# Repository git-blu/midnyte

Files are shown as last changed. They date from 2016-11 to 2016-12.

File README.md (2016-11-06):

# Midnyte LED tablet

Midnyte is an AVR-based resistive touchscreen tablet that uses a 16x24 RGB LED display.
74HC595 shift registers and TLC5940 16-channel PWM LED drivers drive the display and a Semtech SX8652 drives the 4-wire resistive touch panel for user input.
The device can switch between wall power and an internal Li-Ion battery pack.

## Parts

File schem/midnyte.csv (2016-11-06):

Reference | Value | Footprint | Datasheet
P3 | HID | Midnyte:pin_array_4x1_angled
SW3 | +BRIGHTNESS | Midnyte:BUTTON
SW2 | -BRIGHTNESS | Midnyte:BUTTON
RBRIGHT-1 | 100 | SMD:SMD-0402
RDIM-1 | 100 | SMD:SMD-0402
SW1 | RESET | Midnyte:BUTTON
CUCAP1 | 1uF | SMD:SMD-0402
CXTAL1 | 18pF | SMD:SMD-0402
CXTAL2 | 18pF | SMD:SMD-0402
RRESET+1 | 10k | SMD:SMD-0402
RRESET-1 | 100 | SMD:SMD-0402
CVBUS1 | 0.1uF | SMD:SMD-0402
C2 | 0.1uF | SMD:SMD-0402
C4 | 0.1uF | SMD:SMD-0402
C6 | 0.1uF | SMD:SMD-0402
C8 | 0.1uF | SMD:SMD-0402
C10 | 0.1uF | SMD:SMD-0402
C12 | 0.1uF | SMD:SMD-0402
P4 | AVR_JTAG | Midnyte:3220-10-0100-00
X1 | XTAL-2 | Midnyte:CSM-7X
CHID1 | 1uF | SMD:SMD-0402
CHID2 | 0.1uF | SMD:SMD-0402
RTCK1 | 100k | SMD:SMD-0402
RTDO1 | 100k | SMD:SMD-0402
RTMS1 | 100k | SMD:SMD-0402
RTDI1 | 100k | SMD:SMD-0402
U1 | ATmega32U4 | DFN | QFN:QFN-44-1EP
RBRIGHT+1 | 10k | SMD:SMD-0402
RDIM+1 | 10k | SMD:SMD-0402
CBRIGHT1 | 0.1uF | SMD:SMD-0402
CDIM1 | 0.1uF | SMD:SMD-0402
CRESET1 | 0.1uF | SMD:SMD-0402
CON1 | USB-MINI-B | Midnyte:10033526-N3212LF
C1 | 0.1uF | SMD:SMD-0402
C3 | 0.1uF | SMD:SMD-0402
C5 | 0.1uF | SMD:SMD-0402
C7 | 0.1uF | SMD:SMD-0402
C9 | 0.1uF | SMD:SMD-0402
C11 | 0.1uF | SMD:SMD-0402
U4 | 23LC1024 | SOIC:SOIC-8_3.9x4.9mm_Pitch1.27mm
U5 | M25P80 | Midnyte:VDFN-8
RFPROT1 | 10k | SMD:SMD-0402
P1 | HOLE-M3 | Midnyte:HOLE-M3
P2 | HOLE-M3 | Midnyte:HOLE-M3
RHOLD2 | 10k | SMD:SMD-0402
RHOLD1 | 10k | SMD:SMD-0402
U3 | 74HC42 | SOIC:SOIC-16_3.9x9.9mm_Pitch1.27mm
U2 | SX8652 | Midnyte:TDFN14
RNIRQ1 | 10k | SMD:SMD-0402
U8 | LT1939 | Midnyte:DFN12
U7 | LTC4412 | Midnyte:TSOT-23
U6 | MAX8600A | Midnyte:TDFN14
U10 | NCP1529 | Midnyte:UDFN6
U9 | NCP1529 | Midnyte:UDFN6
CPSELECT1 | 47uF | SMD:SMD-0805
CPMIC_IN1 | 2.2uF | SMD:SMD-0402
CSS1 | 0.47uF | SMD:SMD-0402
CVC1 | 220pF | SMD:SMD-0402
RVC1 | 49.9k | SMD:SMD-0402
RRT1 | 40.2k | SMD:SMD-0402
CPMIC1 | 0.47uF | SMD:SMD-0402
L1 | 4.7uH | Midnyte:ASPI-0530LR-4R7M-T2
RPMIC5 | 42.2k | SMD:SMD-0402
RPMIC7 | 8.06k | SMD:SMD-0402
CPMIC3 | 22uF | SMD:SMD-0805
RPMIC3 | 8.06k | SMD:SMD-0402
RPMIC4 | 100k | SMD:SMD-0402
RPMIC6 | 8.06k | SMD:SMD-0402
CPMIC2 | 1uF | SMD:SMD-0402
RPMIC2 | 42.2k | SMD:SMD-0402
CRAIL2 | 10uF | SMD:SMD-0402
CRAIL1 | 10uF | SMD:SMD-0402
CBUCK1 | 4.7uF | SMD:SMD-0402
CBUCK2 | 4.7uF | SMD:SMD-0402
L3 | 2.2uH | Midnyte:LTF5022T-2R2N3R2-LC
L2 | 2.2uH | Midnyte:LTF5022T-2R2N3R2-LC
RFB3 | 4.32M | SMD:SMD-0402
RFB5 | 597k | SMD:SMD-0402
RFB1 | 2.7M | SMD:SMD-0402
RFB2 | 597k | SMD:SMD-0402
D2 | SCHOTTKY | Diodes:Diode-SMA_Standard
Q1 | FQP27P06 | SOT:SOT23_Transistor_RevB_14Mar2014
CCT1 | 680nF | SMD:SMD-0402
RSETI1 | 2k | SMD:SMD-0402
CBAT1 | 2.2uF | SMD:SMD-0402
TH1 | 10k@25C | SMD:SMD-0402
RFLT1 | 100k | SMD:SMD-0402
RCHG1 | 660 | SMD:SMD-0402
D1 | DIODE | SMD:SMD-0402
Q2 | FQP27P06 | SOT:SOT23_Transistor_RevB_14Mar2014
D5 | DIODE | SMD:SMD-0402
D3 | SCHOTTKY | Diodes:Diode-SMA_Standard
D4 | SCHOTTKY | Diodes:Diode-SMA_Standard
RFB4 | 80k | SMD:SMD-0402
CFB2 | 18pF | SMD:SMD-0402
CFB1 | 18pF | SMD:SMD-0402
RPMIC1 | 10k | SMD:SMD-0402
RPOK1 | 10k | SMD:SMD-0402
SW4 | POWER | Midnyte:TO-220
REN1 | 10k | SMD:SMD-0402
RPOWER1 | 10k | SMD:SMD-0402
P5 | BATTERY | Midnyte:1954097-1
K1 | WALL | Midnyte:PJ-002AH-SMT
Q3 | N-CHANNEL_FET | SOT:SOT23_Transistor_RevB_14Mar2014
RPSTATUS1 | 10k | SMD:SMD-0402
CPOWER1 | 0.1uF | SMD:SMD-0402
P6 | ROW0L | Midnyte:pin_array_8x1
P7 | ROW0R | Midnyte:pin_array_8x1
P8 | ROW1L | Midnyte:pin_array_8x1
P9 | ROW1R | Midnyte:pin_array_8x1
P10 | ROW2L | Midnyte:pin_array_8x1
P11 | ROW2R | Midnyte:pin_array_8x1
U11 | 74HC595CS | SMD:TSSOP-16
U14 | 74HC595CS | SMD:TSSOP-16
U12 | 74HC595CS | SMD:TSSOP-16
U15 | 74HC595CS | SMD:TSSOP-16
U13 | 74HC595CS | SMD:TSSOP-16
U16 | 74HC595CS | SMD:TSSOP-16
U17 | TLC5940 | DFN | QFN:QFN-32-1EP
U18 | TLC5940 | DFN | QFN:QFN-32-1EP
U19 | TLC5940 | DFN | QFN:QFN-32-1EP
P12 | RED0L | Midnyte:pin_array_8x1
P13 | RED0R | Midnyte:pin_array_8x1
P14 | GREEN0L | Midnyte:pin_array_8x1
P15 | GREEN0R | Midnyte:pin_array_8x1
P16 | BLUE0L | Midnyte:pin_array_8x1
P17 | BLUE0R | Midnyte:pin_array_8x1
RXERR1 | 10k | SMD:SMD-0402
RXERR2 | 10k | SMD:SMD-0402
RXERR3 | 10k | SMD:SMD-0402
CTLC1 | 0.1uF | SMD:SMD-0402
CTLC2 | 0.1uF | SMD:SMD-0402
CTLC3 | 0.1uF | SMD:SMD-0402
IREF1 | 7.68k | SMD:SMD-0402
IREF2 | 7.68k | SMD:SMD-0402
IREF3 | 7.68k | SMD:SMD-0402
RBLANK1 | 10k | SMD:SMD-0402
RBLANK2 | 10k | SMD:SMD-0402
RBLANK3 | 10k | SMD:SMD-0402
U20 | TLC5940 | DFN | QFN:QFN-32-1EP
U21 | TLC5940 | DFN | QFN:QFN-32-1EP
U22 | TLC5940 | DFN | QFN:QFN-32-1EP
P18 | RED1L | Midnyte:pin_array_8x1
P19 | RED1R | Midnyte:pin_array_8x1
P20 | GREEN1L | Midnyte:pin_array_8x1
P21 | GREEN1R | Midnyte:pin_array_8x1
P22 | BLUE1L | Midnyte:pin_array_8x1
P23 | BLUE1R | Midnyte:pin_array_8x1
RXERR4 | 10k | SMD:SMD-0402
RXERR5 | 10k | SMD:SMD-0402
RXERR6 | 10k | SMD:SMD-0402
CTLC4 | 0.1uF | SMD:SMD-0402
CTLC5 | 0.1uF | SMD:SMD-0402
CTLC6 | 0.1uF | SMD:SMD-0402
IREF4 | 7.68k | SMD:SMD-0402
IREF5 | 7.68k | SMD:SMD-0402
IREF6 | 7.68k | SMD:SMD-0402
RBLANK4 | 10k | SMD:SMD-0402
RBLANK5 | 10k | SMD:SMD-0402
RBLANK6 | 10k | SMD:SMD-0402
U23 | TLC5940 | DFN | QFN:QFN-32-1EP
U24 | TLC5940 | DFN | QFN:QFN-32-1EP
U25 | TLC5940 | DFN | QFN:QFN-32-1EP
P24 | RED2L | Midnyte:pin_array_8x1
P25 | RED2R | Midnyte:pin_array_8x1
P26 | GREEN2L | Midnyte:pin_array_8x1
P27 | GREEN2R | Midnyte:pin_array_8x1
P28 | BLUE2L | Midnyte:pin_array_8x1
P29 | BLUE2R | Midnyte:pin_array_8x1
RXERR7 | 10k | SMD:SMD-0402
RXERR8 | 10k | SMD:SMD-0402
RXERR9 | 10k | SMD:SMD-0402
CTLC7 | 0.1uF | SMD:SMD-0402
CTLC8 | 0.1uF | SMD:SMD-0402
CTLC9 | 0.1uF | SMD:SMD-0402
IREF7 | 7.68k | SMD:SMD-0402
IREF8 | 7.68k | SMD:SMD-0402
IREF9 | 7.68k | SMD:SMD-0402
RBLANK7 | 10k | SMD:SMD-0402
RBLANK8 | 10k | SMD:SMD-0402
RBLANK9 | 10k | SMD:SMD-0402

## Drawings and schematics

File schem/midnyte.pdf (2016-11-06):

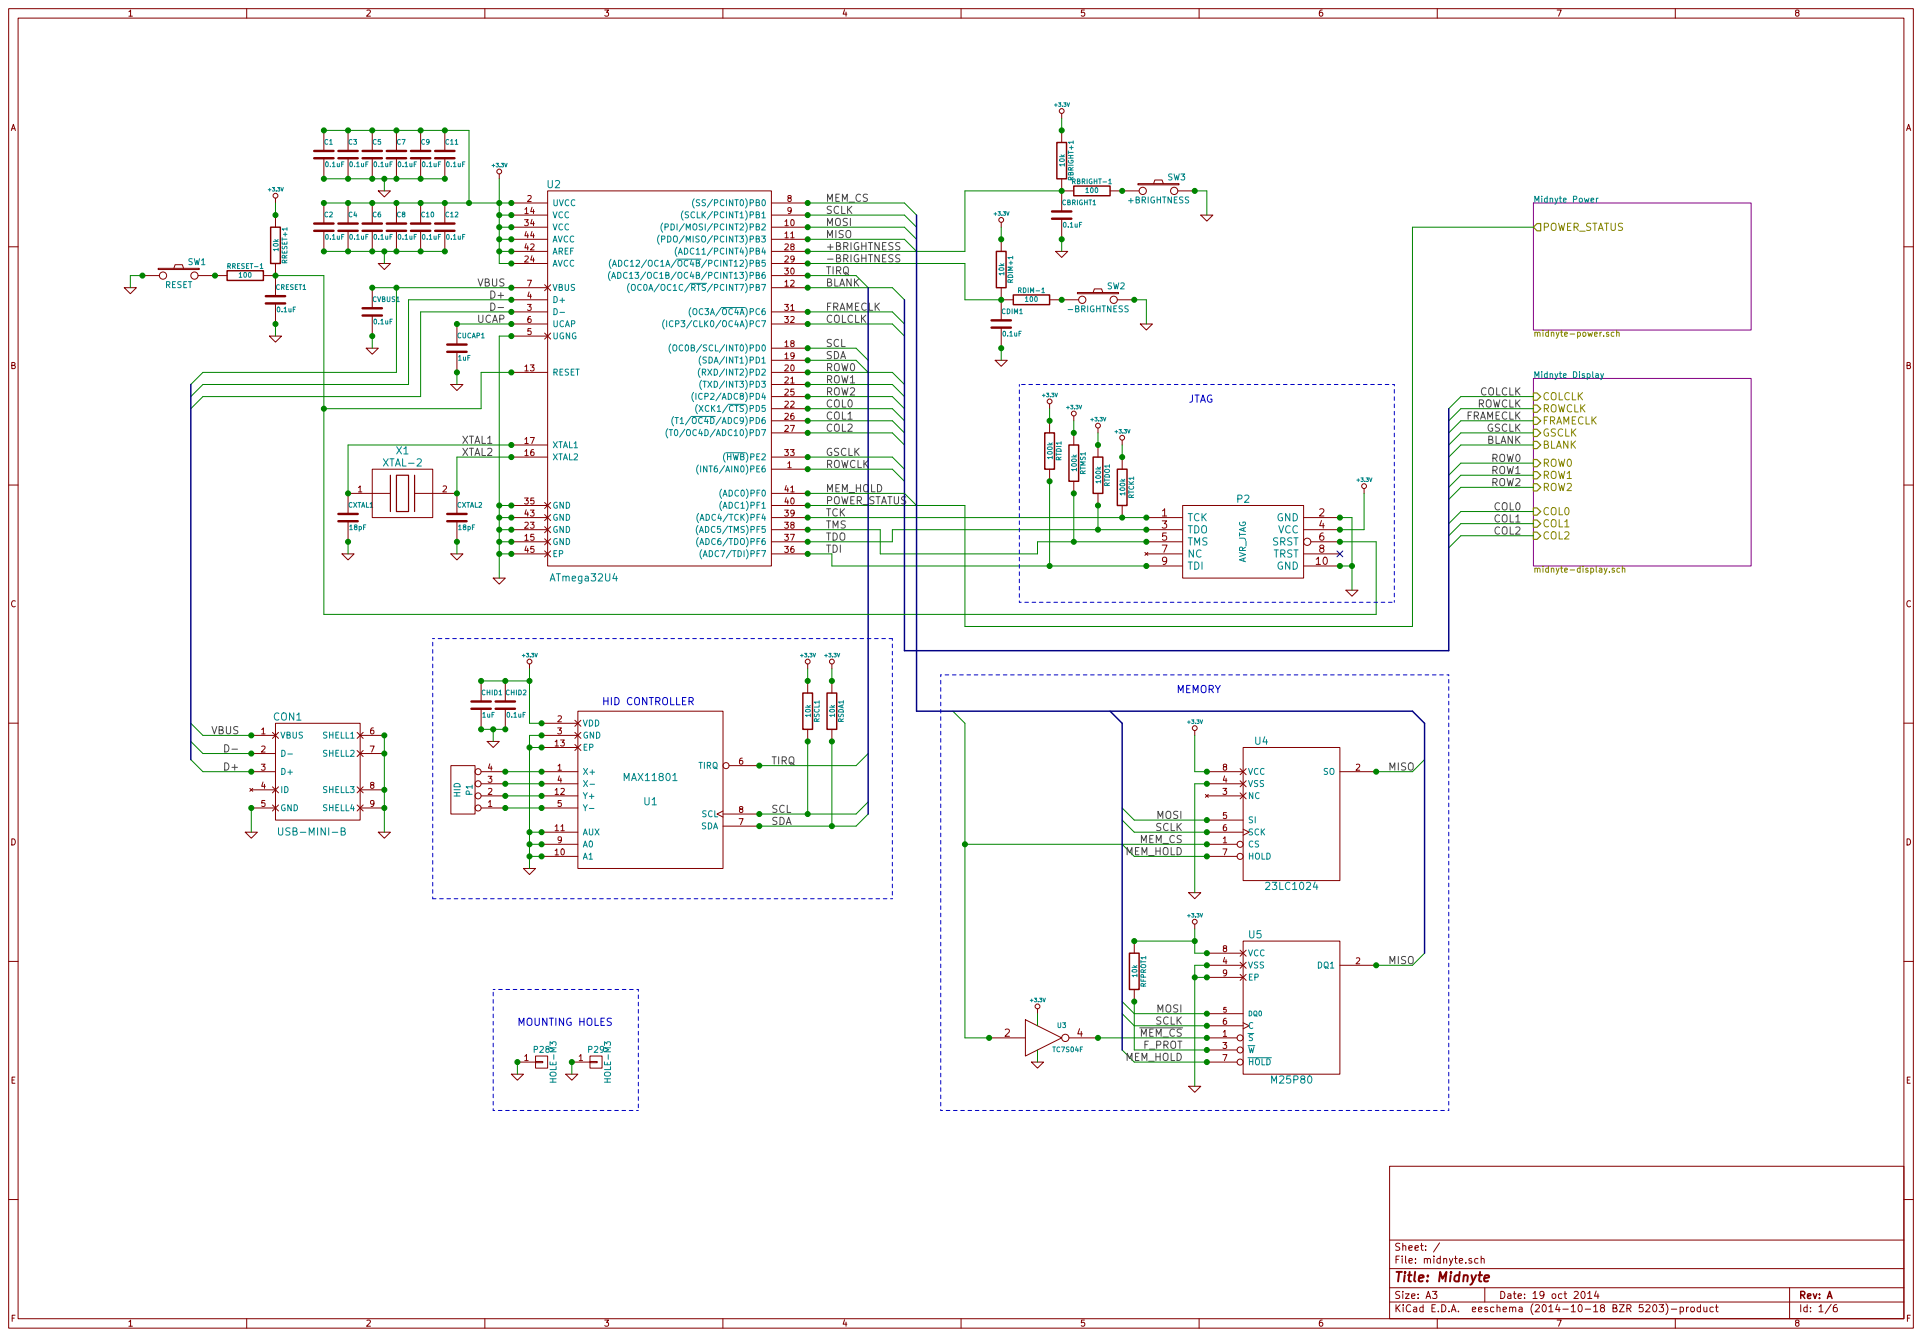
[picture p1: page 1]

+3.3V | JTAG

TCK

File: midnyte.sch Sheet: /
Id: 1/6 Title: Midnyte

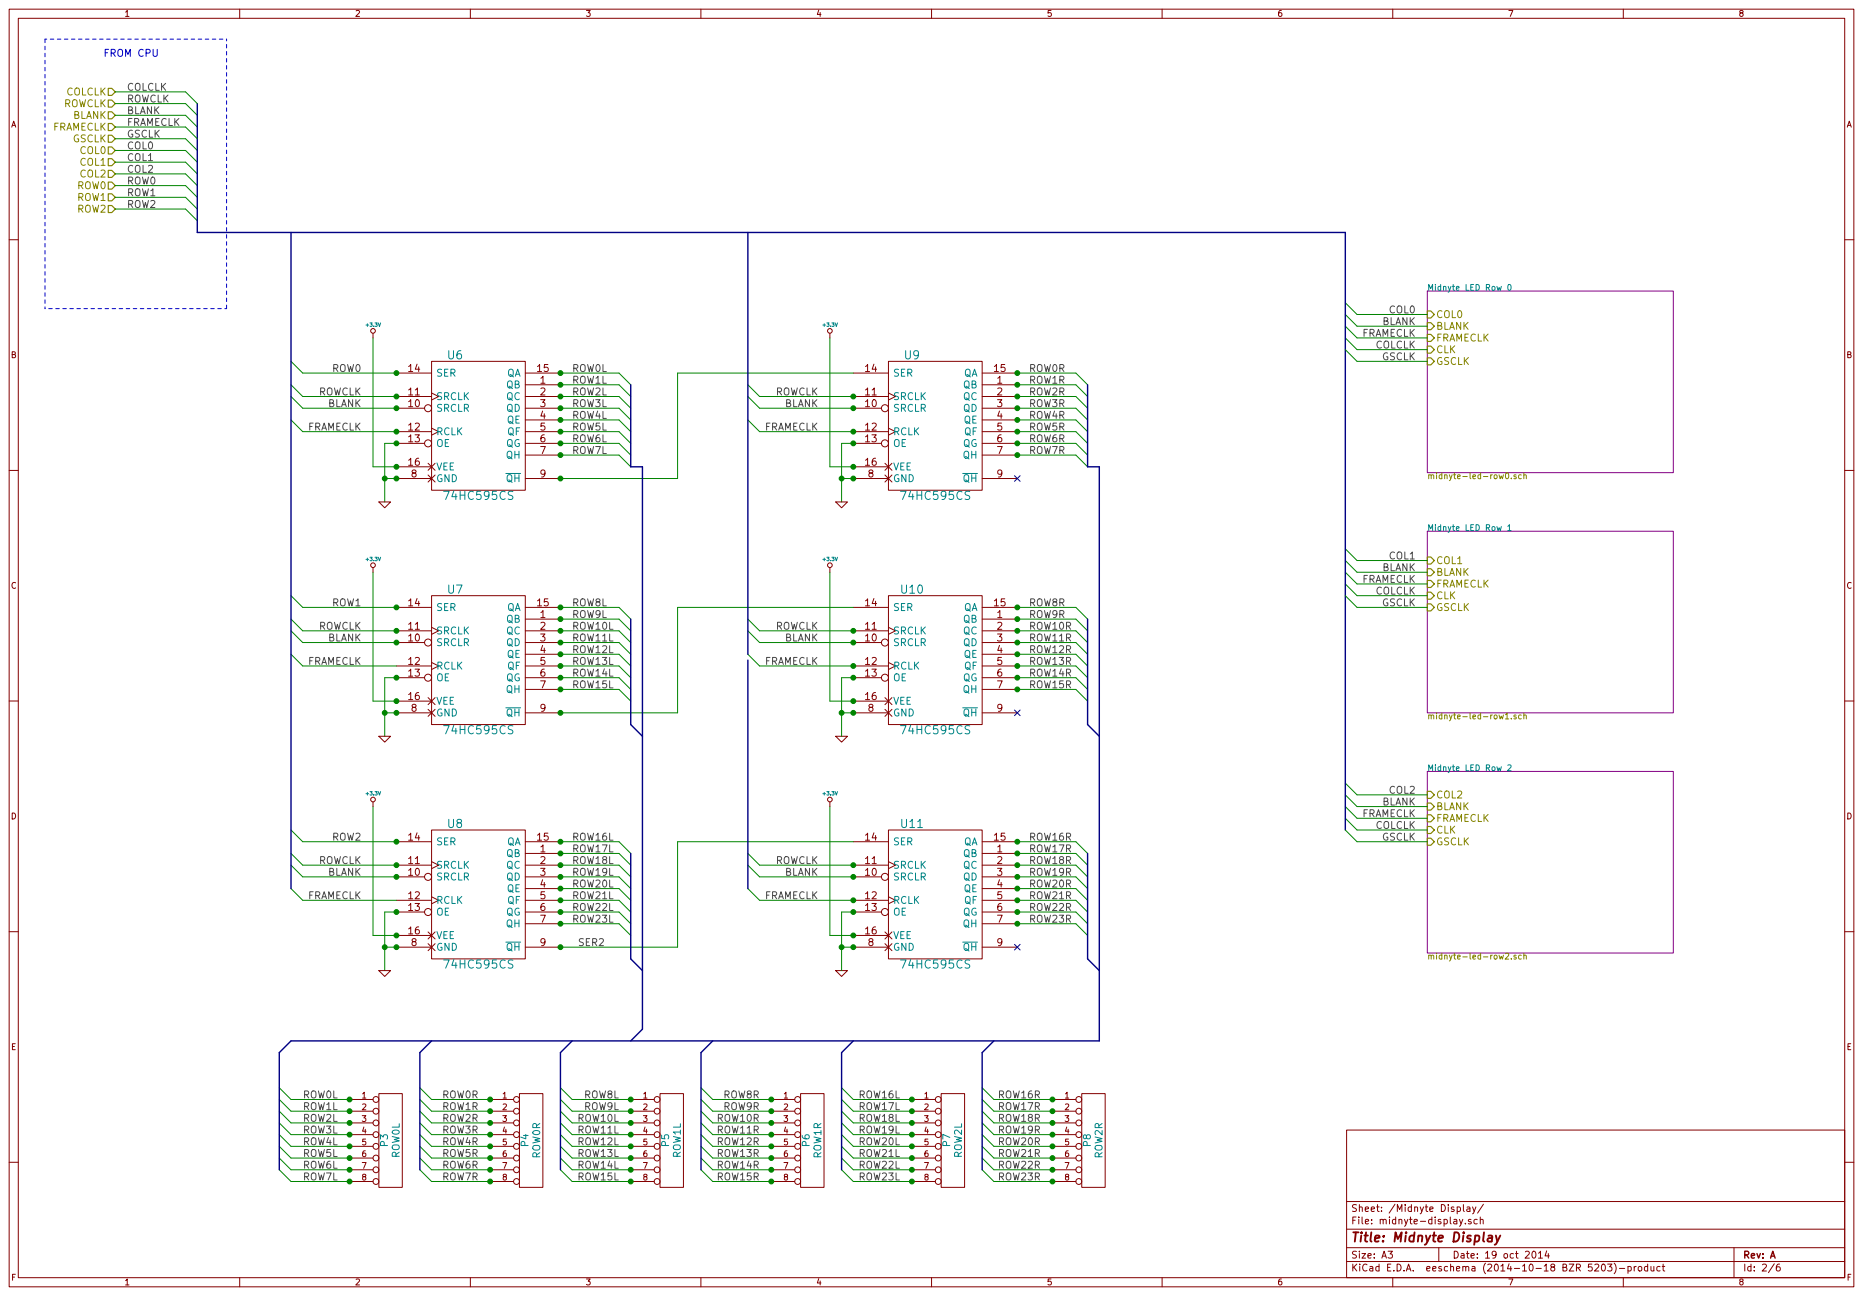
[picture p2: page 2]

Midnyte LED Row 0 midnyte-led-row0.sch COL0 BLANK
FRAMECLK COLCLK COL0 BLANK
FRAMECLK COLCLK COL2 BLANK
FRAMECLK CLK GSCLK Midnyte LED Row 2 midnyte-led-row2.sch COL2 BLANK

Midnyte LED Row 1 midnyte-led-row1.sch COL1 BLANK
FRAMECLK GSCLK

File: midnyte-display.sch Sheet: /Midnyte Display/
Id: 2/6 Title: Midnyte Display

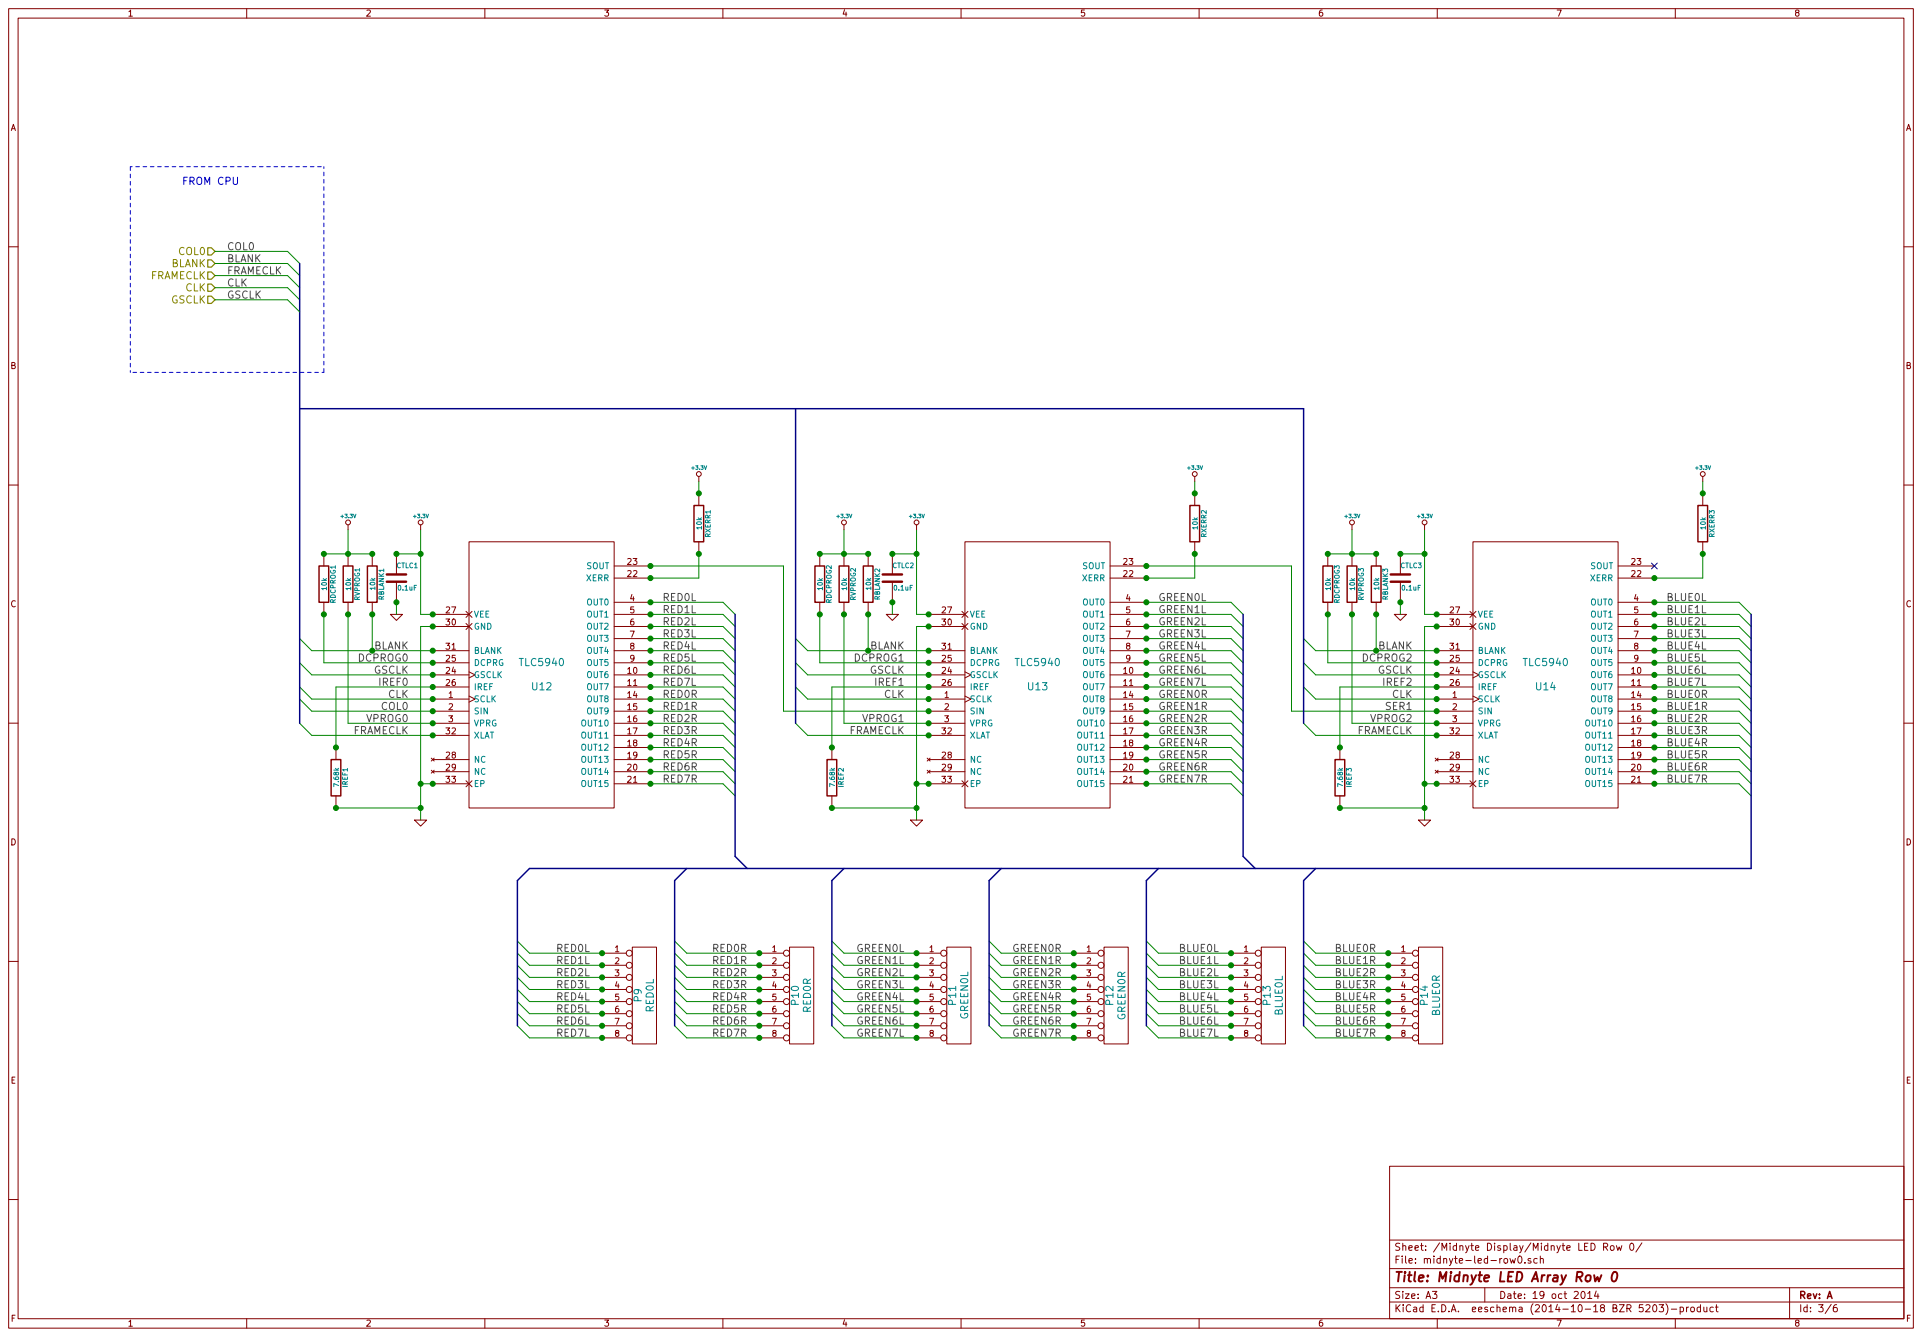
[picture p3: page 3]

File: midnyte-led-row0.sch Sheet: /Midnyte Display/Midnyte LED Row 0/
Id: 3/6 Title: Midnyte LED Array Row 0

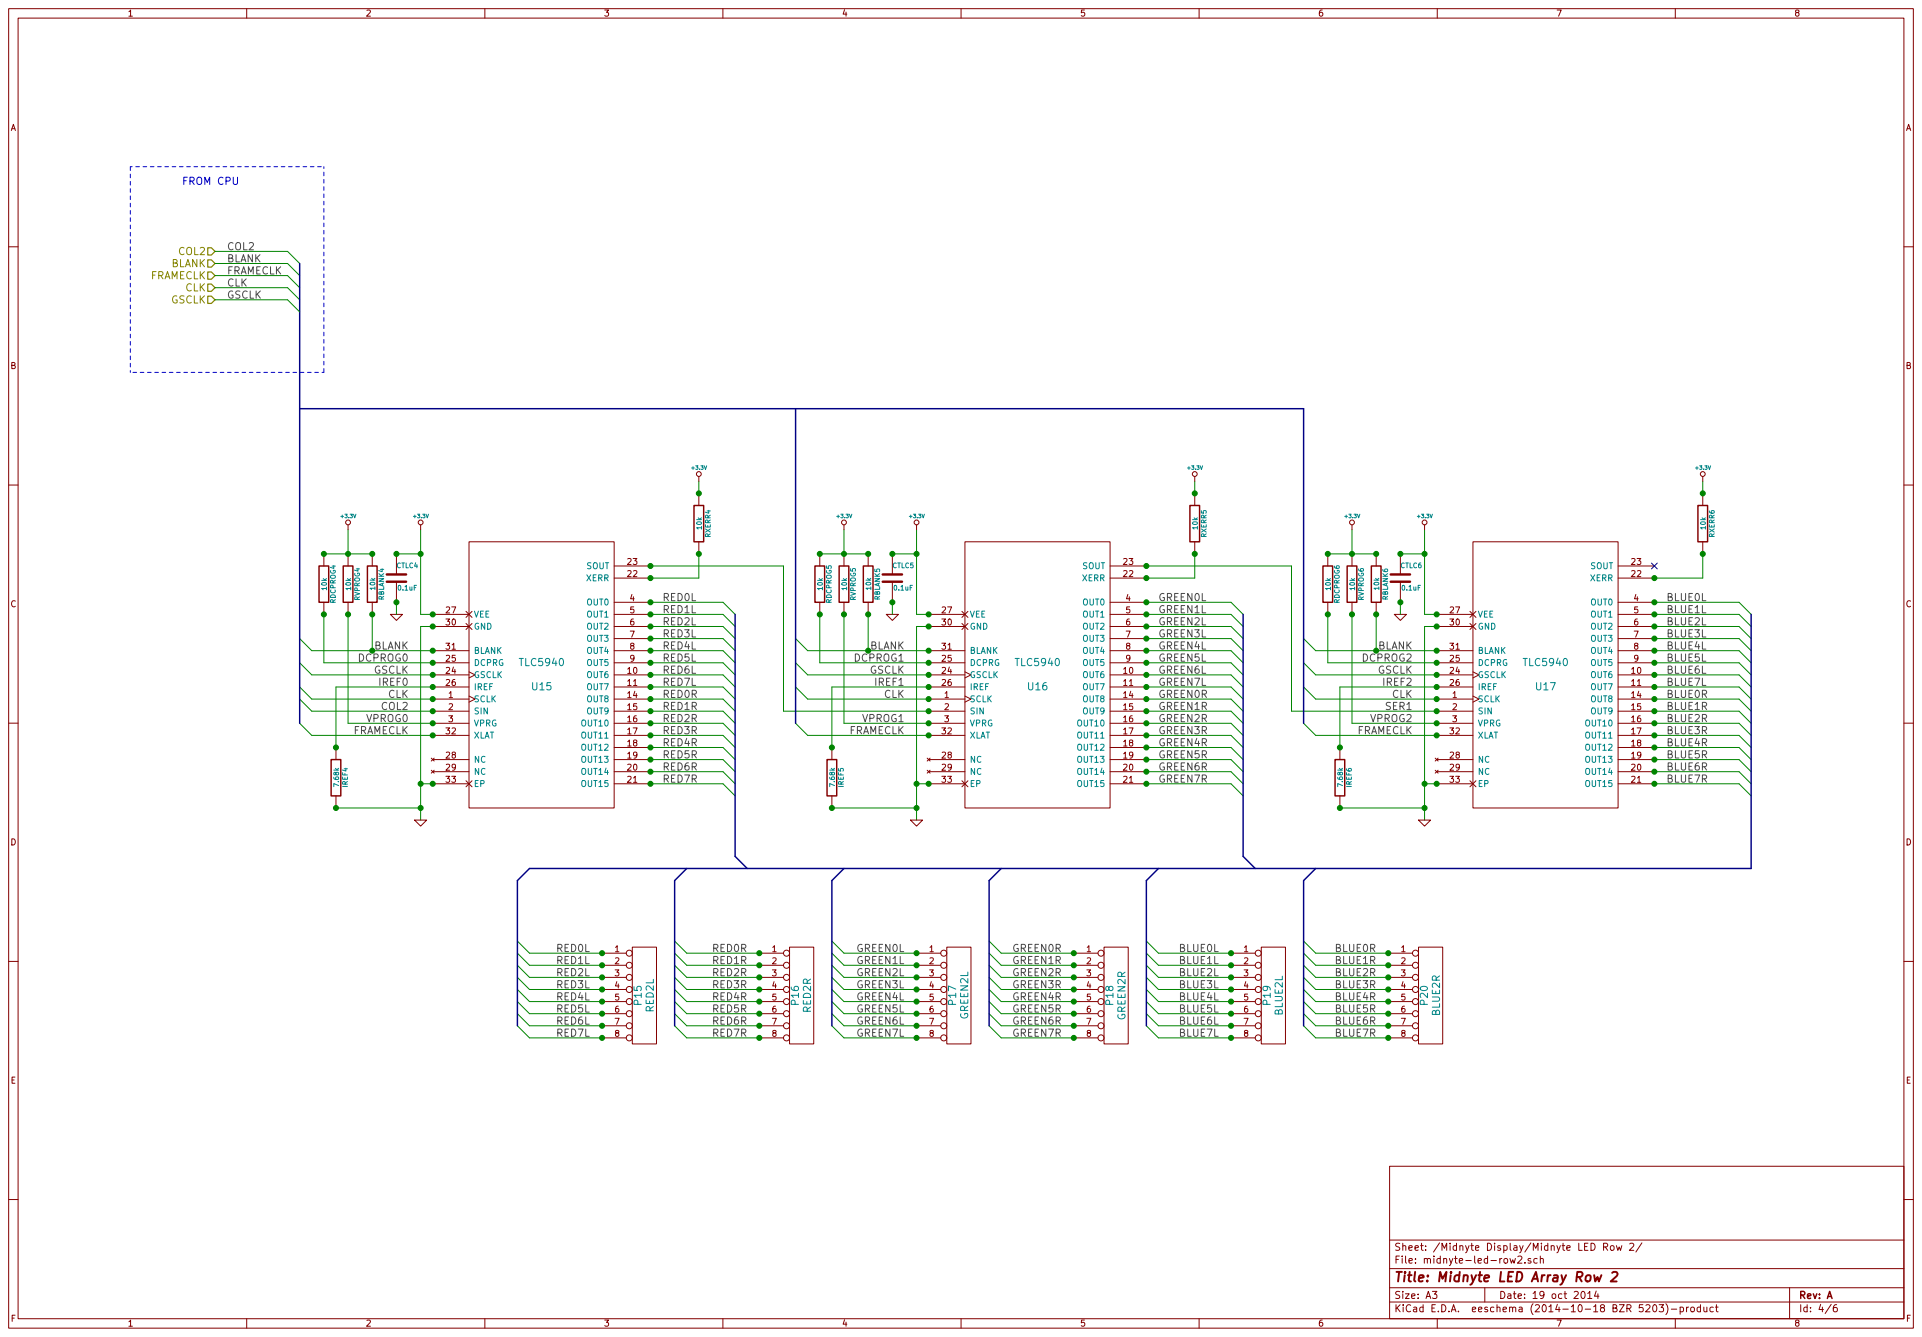
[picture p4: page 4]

File: midnyte-led-row2.sch Sheet: /Midnyte Display/Midnyte LED Row 2/
Id: 4/6 Title: Midnyte LED Array Row 2

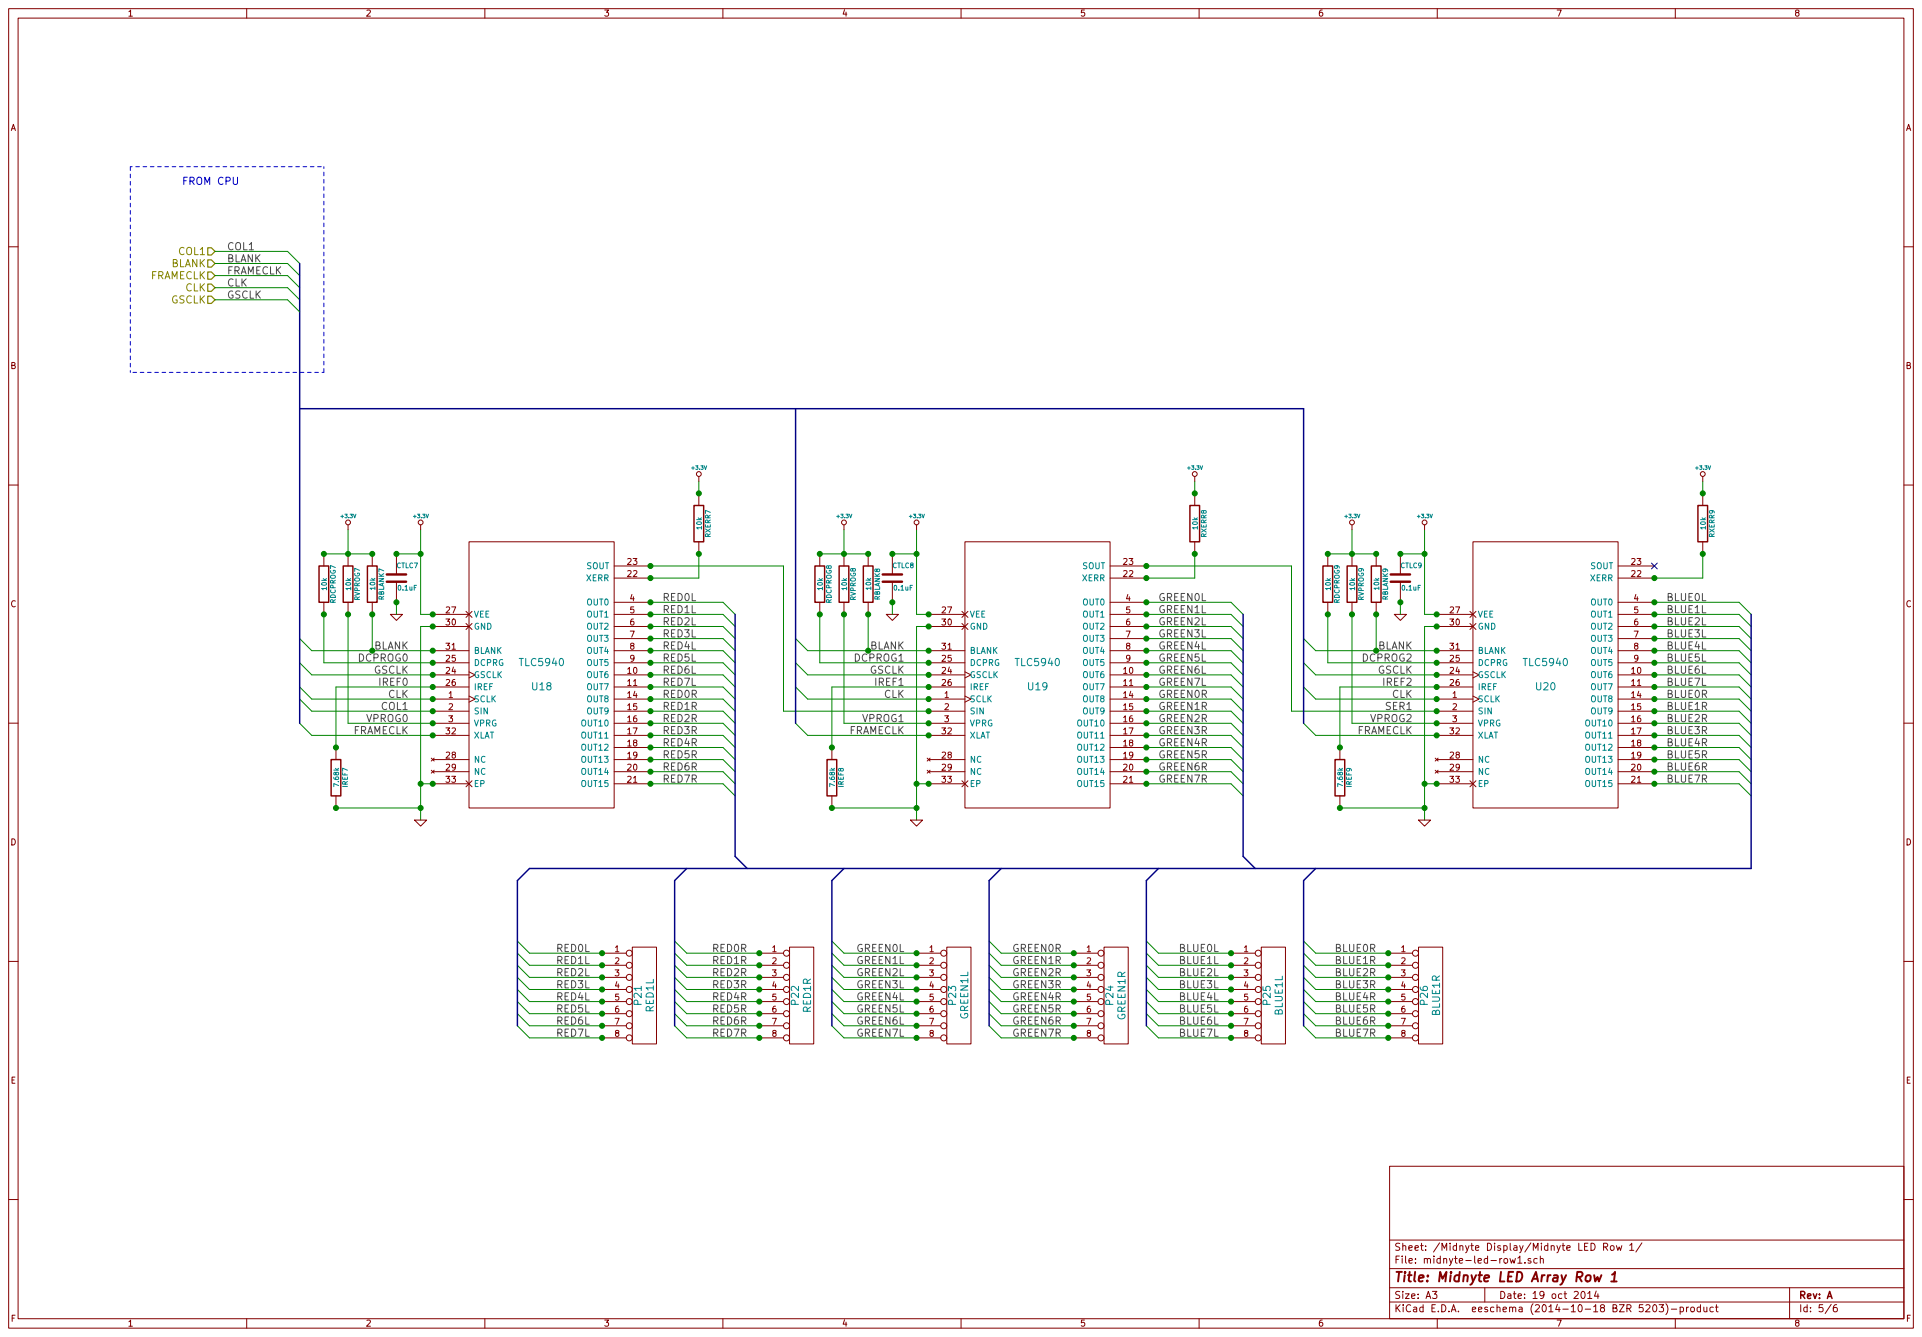
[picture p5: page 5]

File: midnyte-led-row1.sch Sheet: /Midnyte Display/Midnyte LED Row 1/
Id: 5/6 Title: Midnyte LED Array Row 1

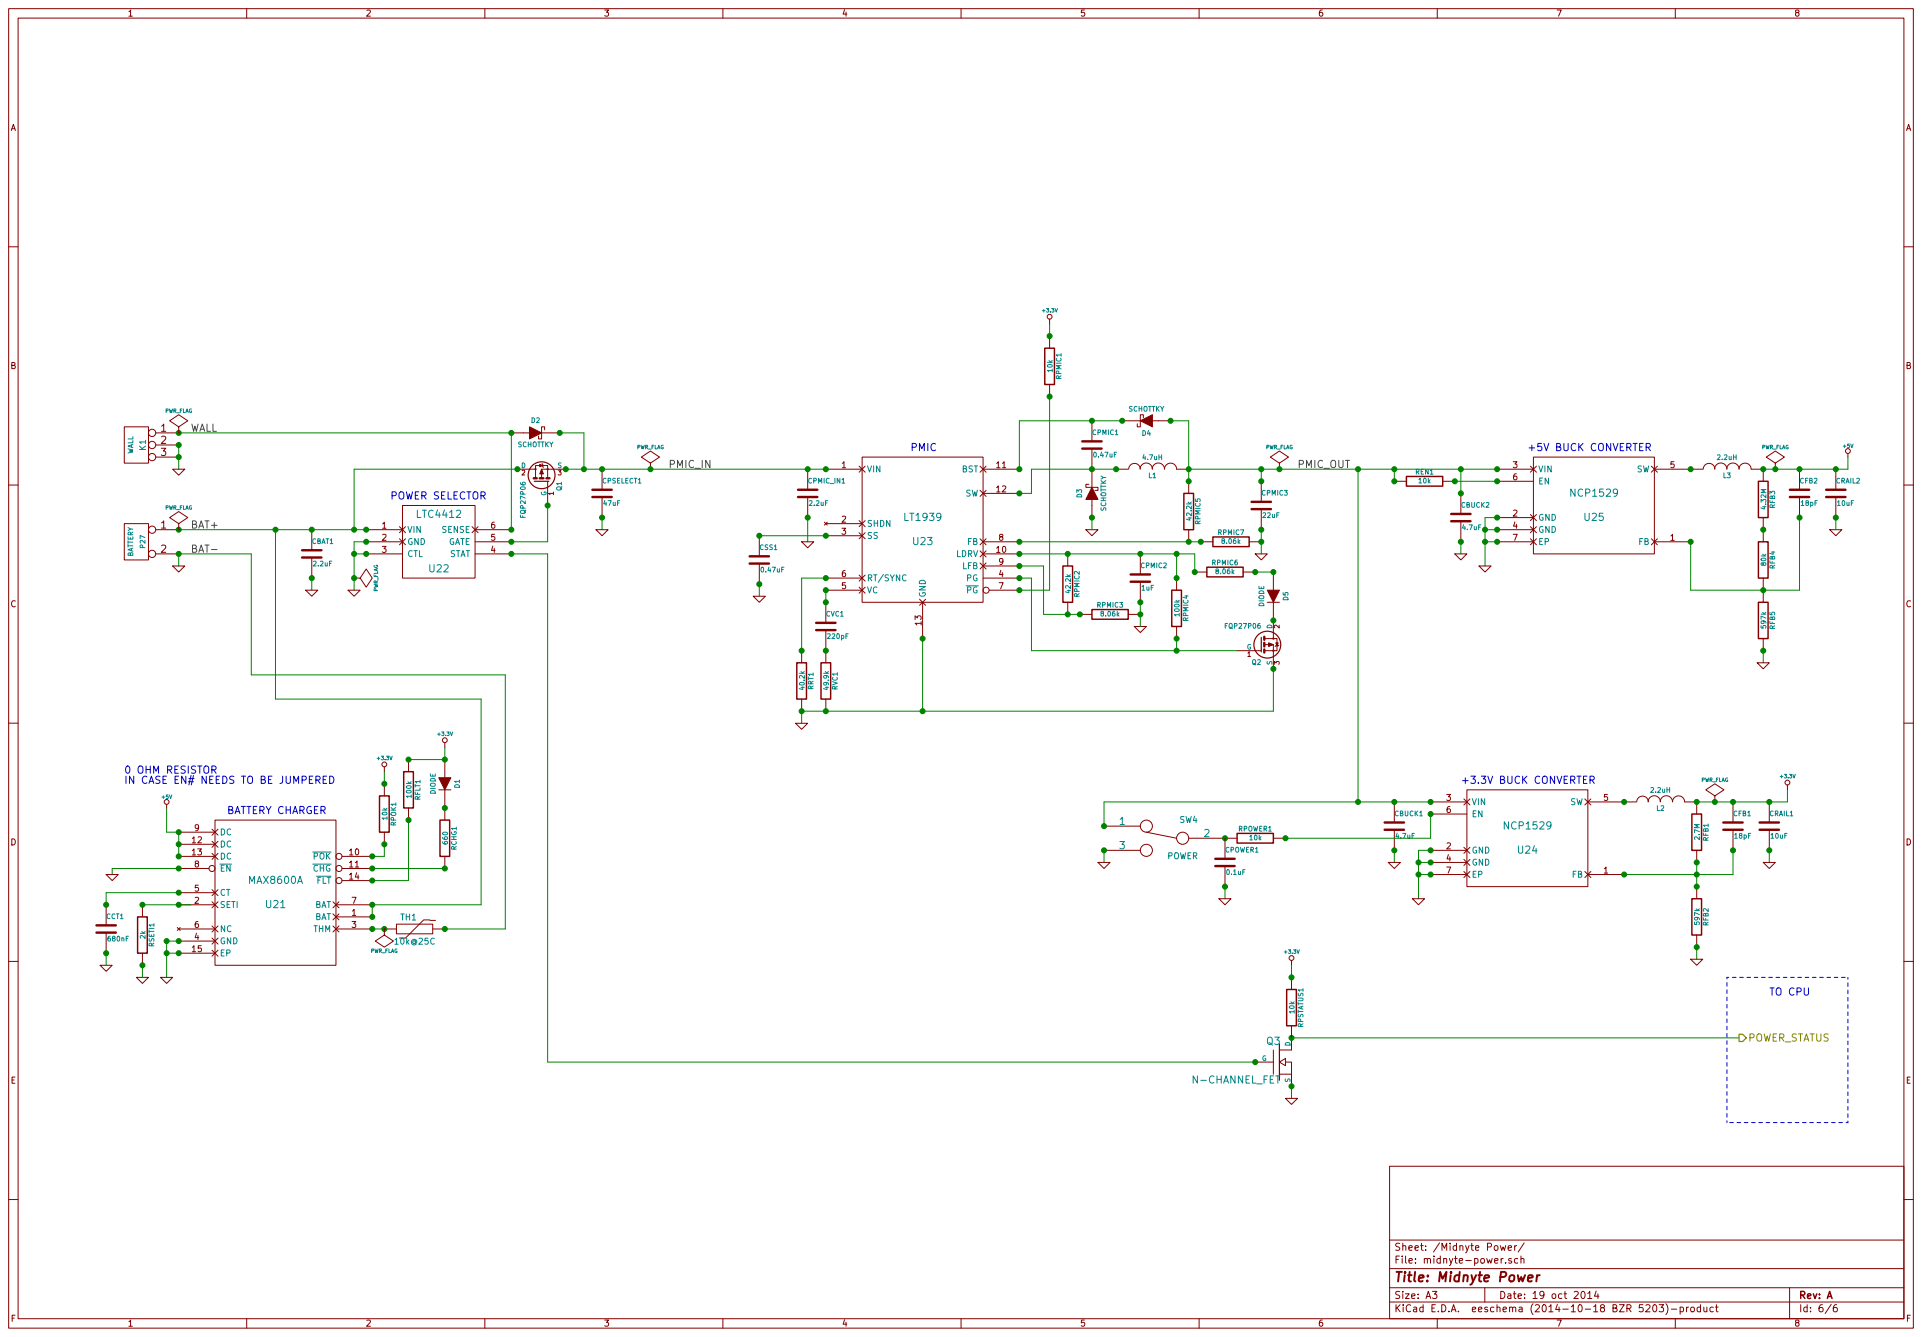
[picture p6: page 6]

IN CASE EN# NEEDS TO BE JUMPERED

Id: 6/6 Title: Midnyte Power File: midnyte-power.sch Sheet: /Midnyte Power/

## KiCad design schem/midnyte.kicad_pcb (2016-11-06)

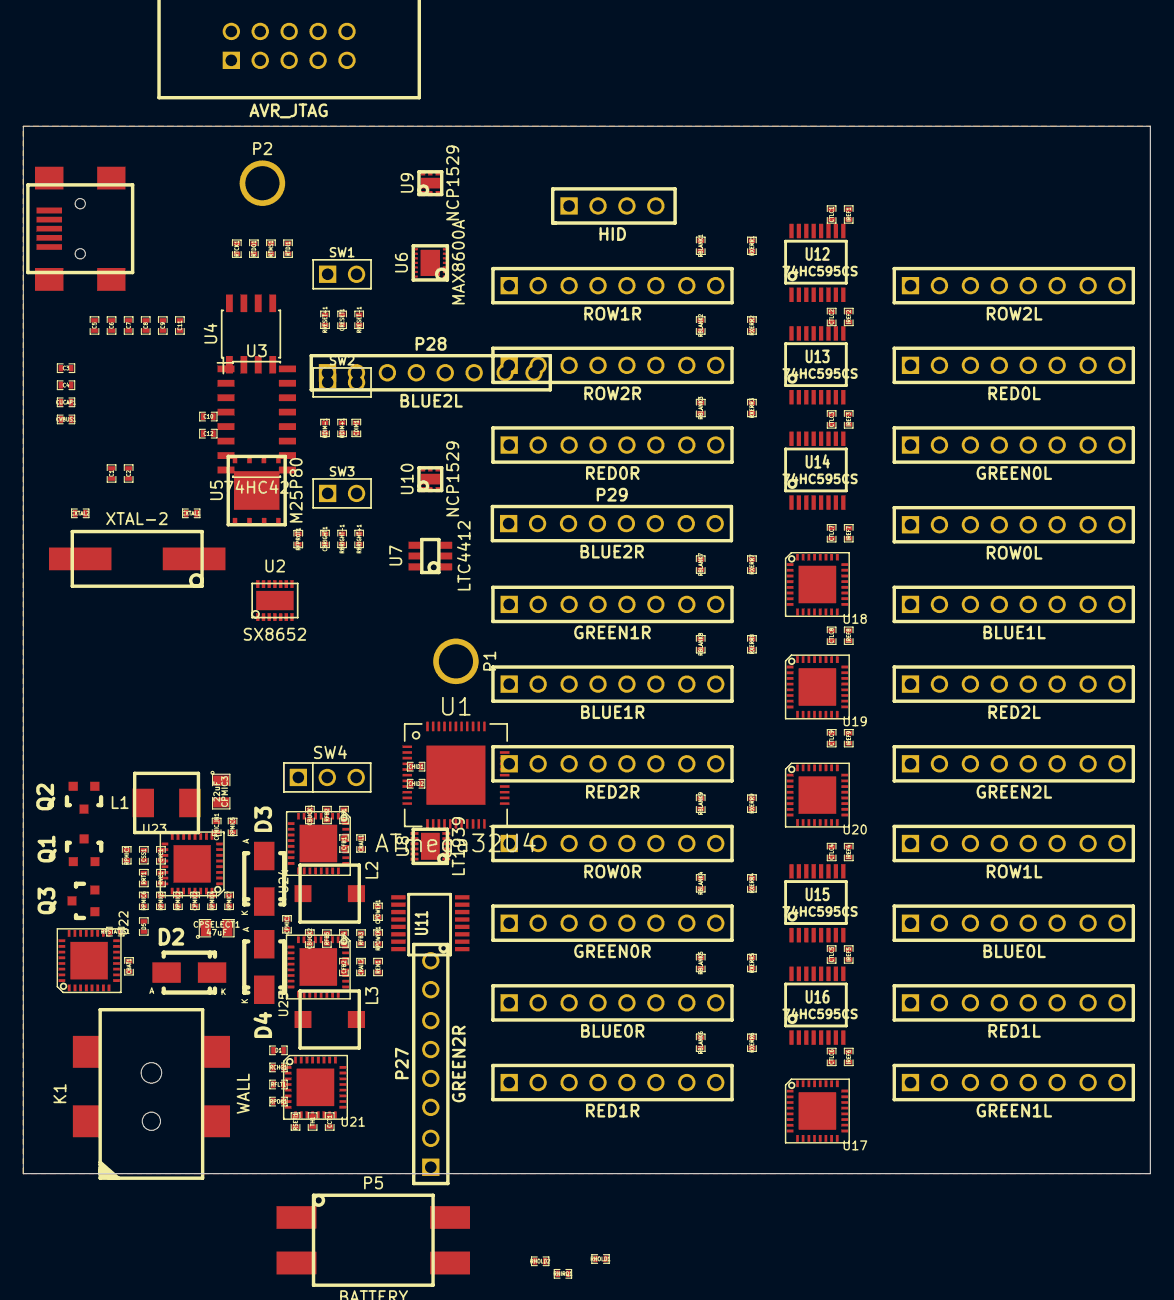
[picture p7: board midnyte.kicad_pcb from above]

Board: 4 copper layers, 99.0 x 92.0 mm, 181 parts (0 on the bottom side), 302 nets, no tracks yet.

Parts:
C1, C2, C3, C4, C5, C6, C7, C8, C9, C10, C11, C12: 0.1uF; SMD-0402
CBAT1: 2.2uF; SMD-0402
CBRIGHT1: 0.1uF; SMD-0402
CBUCK1, CBUCK2: 4.7uF; SMD-0402
CCT1: 680nF; SMD-0402
CDIM1: 0.1uF; SMD-0402
CFB1, CFB2: 18pF; SMD-0402
CHID1: 1uF; SMD-0402
CHID2: 0.1uF; SMD-0402
CON1: USB-MINI-B; 10033526-N3212LF
CPMIC1: 0.47uF; SMD-0402
CPMIC2: 1uF; SMD-0402
CPMIC3: 22uF; SMD-0805
CPMIC_IN1: 2.2uF; SMD-0402
CPOWER1: 0.1uF; SMD-0402
CPSELECT1: 47uF; SMD-0805
CRAIL1, CRAIL2: 10uF; SMD-0402
CRESET1: 0.1uF; SMD-0402
CSS1: 0.47uF; SMD-0402
CTLC1, CTLC2, CTLC3, CTLC4, CTLC5, CTLC6, CTLC7, CTLC8, CTLC9: 0.1uF; SMD-0402
CUCAP1: 1uF; SMD-0402
CVBUS1: 0.1uF; SMD-0402
CVC1: 220pF; SMD-0402
CXTAL1, CXTAL2: 18pF; SMD-0402
D1, D5: DIODE; SMD-0402
D2, D3, D4: SCHOTTKY; Diode-SMA_Standard
IREF1, IREF2, IREF3, IREF4, IREF5, IREF6, IREF7, IREF8, IREF9: 7.68k; SMD-0402
K1: WALL; PJ-002AH-SMT
L1: 4.7uH; ASPI-0530LR-4R7M-T2
L2, L3: 2.2uH; LTF5022T-2R2N3R2-LC
P1, P2: HOLE-M3
P3: HID; pin_array_4x1
P4: AVR_JTAG; 302-S101
P5: BATTERY; 1954097-1
P6: ROW0L; pin_array_8x1
P7: ROW0R; pin_array_8x1
P8: ROW1L; pin_array_8x1
P9: ROW1R; pin_array_8x1
P10: ROW2L; pin_array_8x1
P11: ROW2R; pin_array_8x1
P12: RED0L; pin_array_8x1
P13: RED0R; pin_array_8x1
P14: GREEN0L; pin_array_8x1
P15: GREEN0R; pin_array_8x1
P16: BLUE0L; pin_array_8x1
P17: BLUE0R; pin_array_8x1
P18: RED1L; pin_array_8x1
P19: RED1R; pin_array_8x1
P20: GREEN1L; pin_array_8x1
P21: GREEN1R; pin_array_8x1
P22: BLUE1L; pin_array_8x1
P23: BLUE1R; pin_array_8x1
P24: RED2L; pin_array_8x1
P25: RED2R; pin_array_8x1
P26: GREEN2L; pin_array_8x1
P27: GREEN2R; pin_array_8x1
P28: BLUE2L; pin_array_8x1
P29: BLUE2R; pin_array_8x1
Q1, Q2: FQP27P06; SOT23_Transistor_RevB_14Mar2014
Q3: N-CHANNEL_FET; SOT23_Transistor_RevB_14Mar2014
RBLANK1, RBLANK2, RBLANK3, RBLANK4, RBLANK5, RBLANK6, RBLANK7, RBLANK8, RBLANK9: 10k; SMD-0402
RBRIGHT+1: 10k; SMD-0402
RBRIGHT-1: 100; SMD-0402
RCHG1: 660; SMD-0402
RDIM+1: 10k; SMD-0402
RDIM-1: 100; SMD-0402
REN1: 10k; SMD-0402
RFB1: 2.7M; SMD-0402
RFB2, RFB5: 597k; SMD-0402
RFB3: 4.32M; SMD-0402
RFB4: 80k; SMD-0402
RFLT1: 100k; SMD-0402
RFPROT1: 10k; SMD-0402
RHOLD1, RHOLD2: 10k; SMD-0402
RNIRQ1: 10k; SMD-0402
RPMIC1: 10k; SMD-0402
RPMIC2, RPMIC5: 42.2k; SMD-0402
RPMIC3, RPMIC6, RPMIC7: 8.06k; SMD-0402
RPMIC4: 100k; SMD-0402
RPOK1: 10k; SMD-0402
RPOWER1: 10k; SMD-0402
RPSTATUS1: 10k; SMD-0402
RRESET+1: 10k; SMD-0402
RRESET-1: 100; SMD-0402
RRT1: 40.2k; SMD-0402
RSETI1: 2k; SMD-0402
RTCK1: 100k; SMD-0402
RTDI1: 100k; SMD-0402
RTDO1: 100k; SMD-0402
RTMS1: 100k; SMD-0402
RVC1: 49.9k; SMD-0402
RXERR1, RXERR2, RXERR3, RXERR4, RXERR5, RXERR6, RXERR7, RXERR8, RXERR9: 10k; SMD-0402
SW1: RESET; pin_array_1x02
SW2: -BRIGHTNESS; pin_array_1x02
SW3: +BRIGHTNESS; pin_array_1x02
SW4: POWER; pin_array_1x03
TH1: 10k@25C; SMD-0402
U1: ATmega32U4; QFN-44-1EP
U2: SX8652
U3: 74HC42; SOIC-16_3.9x9.9mm_Pitch1.27mm
U4: 23LC1024; SOIC-8_3.9x4.9mm_Pitch1.27mm
U5: M25P80; VDFN-8
U6: MAX8600A; TDFN14
U7: LTC4412; TSOT-23
U8: LT1939; DFN12
U9, U10: NCP1529; UDFN6
U11, U12, U13, U14, U15, U16: 74HC595CS; TSSOP-16
U17, U18, U19, U20, U21, U22, U23, U24, U25: TLC5940; QFN-32-1EP
X1: XTAL-2; CSM-7X

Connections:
+3.3V: C1.1, C2.1, C3.1, C4.1, C5.1, C6.1, C7.1, C8.1, C9.1, C10.1, C11.1, C12.1, CFB1.1, CHID1.1, CHID2.1, CRAIL1.1, CTLC1.1, CTLC2.1, CTLC3.1, CTLC4.1, CTLC5.1, CTLC6.1, CTLC7.1, CTLC8.1, CTLC9.1, D1.1, L2.2, P4.4, RBLANK1.1, RBLANK2.1, RBLANK3.1, RBLANK4.1, RBLANK5.1, RBLANK6.1, RBLANK7.1, RBLANK8.1, RBLANK9.1, RBRIGHT+1.1, RDIM+1.1, RFB1.1, RFLT1.1, RFPROT1.1, RHOLD1.1, RHOLD2.1, RNIRQ1.1, RPMIC1.1, RPOK1.1, RPSTATUS1.1, RRESET+1.1, RTCK1.1, RTDI1.1, RTDO1.1, RTMS1.1, RXERR1.1, RXERR2.1, RXERR3.1, RXERR4.1, RXERR5.1, RXERR6.1, RXERR7.1, RXERR8.1, RXERR9.1, U1.2, U1.14, U1.24, U1.34, U1.42, U1.44, U2.2, U3.16, U4.8, U5.8, U11.16, U12.16, U13.16, U14.16, U15.16, U16.16, U17.27, U18.27, U19.27, U20.27, U21.27, U22.27, U23.27, U24.27, U25.27
+5V: CFB2.1, CRAIL2.1, L3.2, RFB3.1, U6.9, U6.12, U6.13
/+BRIGHTNESS: CBRIGHT1.1, RBRIGHT+1.2, RBRIGHT-1.1, U1.28
/-BRIGHTNESS: CDIM1.1, RDIM+1.2, RDIM-1.1, U1.29
/D+: CON1.3, U1.4
/D-: CON1.2, U1.3
/F_PROT: RFPROT1.2, U5.3
/MEM_CS0: U1.8, U3.15
/MEM_CS1: U1.40, U3.14
/MISO: U1.11, U2.10, U4.2, U5.2
/MOSI: U1.10, U2.9, U4.5, U5.5
/Midnyte Display/BLANK: RBLANK1.2, RBLANK2.2, RBLANK3.2, RBLANK4.2, RBLANK5.2, RBLANK6.2, RBLANK7.2, RBLANK8.2, RBLANK9.2, U1.18, U11.10, U12.10, U13.10, U14.10, U15.10, U16.10, U17.31, U18.31, U19.31, U20.31, U21.31, U22.31, U23.31, U24.31, U25.31
/Midnyte Display/COL0: U1.22, U17.2
/Midnyte Display/COL1: U1.26, U20.2
/Midnyte Display/COL2: U1.27, U23.2
/Midnyte Display/COLCLK: U1.32, U17.1, U18.1, U19.1, U20.1, U21.1, U22.1, U23.1, U24.1, U25.1
/Midnyte Display/DCPROG: U1.19, U17.25, U18.25, U19.25, U20.25, U21.25, U22.25, U23.25, U24.25, U25.25
/Midnyte Display/FRAMECLK: U1.31, U11.12, U12.12, U13.12, U14.12, U15.12, U16.12, U17.32, U18.32, U19.32, U20.32, U21.32, U22.32, U23.32, U24.32, U25.32
/Midnyte Display/GSCLK: U1.33, U17.24, U18.24, U19.24, U20.24, U21.24, U22.24, U23.24, U24.24, U25.24
/Midnyte Display/Midnyte LED Row 0/BLUE0L: P16.1, U19.4
/Midnyte Display/Midnyte LED Row 0/BLUE0R: P17.1, U19.14
/Midnyte Display/Midnyte LED Row 0/BLUE1L: P16.2, U19.5
/Midnyte Display/Midnyte LED Row 0/BLUE1R: P17.2, U19.15
/Midnyte Display/Midnyte LED Row 0/BLUE2L: P16.3, U19.6
/Midnyte Display/Midnyte LED Row 0/BLUE2R: P17.3, U19.16
/Midnyte Display/Midnyte LED Row 0/BLUE3L: P16.4, U19.7
/Midnyte Display/Midnyte LED Row 0/BLUE3R: P17.4, U19.17
/Midnyte Display/Midnyte LED Row 0/BLUE4L: P16.5, U19.8
/Midnyte Display/Midnyte LED Row 0/BLUE4R: P17.5, U19.18
/Midnyte Display/Midnyte LED Row 0/BLUE5L: P16.6, U19.9
/Midnyte Display/Midnyte LED Row 0/BLUE5R: P17.6, U19.19
/Midnyte Display/Midnyte LED Row 0/BLUE6L: P16.7, U19.10
/Midnyte Display/Midnyte LED Row 0/BLUE6R: P17.7, U19.20
/Midnyte Display/Midnyte LED Row 0/BLUE7L: P16.8, U19.11
/Midnyte Display/Midnyte LED Row 0/BLUE7R: P17.8, U19.21
/Midnyte Display/Midnyte LED Row 0/GREEN0L: P14.1, U18.4
/Midnyte Display/Midnyte LED Row 0/GREEN0R: P15.1, U18.14
/Midnyte Display/Midnyte LED Row 0/GREEN1L: P14.2, U18.5
/Midnyte Display/Midnyte LED Row 0/GREEN1R: P15.2, U18.15
/Midnyte Display/Midnyte LED Row 0/GREEN2L: P14.3, U18.6
/Midnyte Display/Midnyte LED Row 0/GREEN2R: P15.3, U18.16
/Midnyte Display/Midnyte LED Row 0/GREEN3L: P14.4, U18.7
/Midnyte Display/Midnyte LED Row 0/GREEN3R: P15.4, U18.17
/Midnyte Display/Midnyte LED Row 0/GREEN4L: P14.5, U18.8
/Midnyte Display/Midnyte LED Row 0/GREEN4R: P15.5, U18.18
/Midnyte Display/Midnyte LED Row 0/GREEN5L: P14.6, U18.9
/Midnyte Display/Midnyte LED Row 0/GREEN5R: P15.6, U18.19
/Midnyte Display/Midnyte LED Row 0/GREEN6L: P14.7, U18.10
/Midnyte Display/Midnyte LED Row 0/GREEN6R: P15.7, U18.20
/Midnyte Display/Midnyte LED Row 0/GREEN7L: P14.8, U18.11
/Midnyte Display/Midnyte LED Row 0/GREEN7R: P15.8, U18.21
/Midnyte Display/Midnyte LED Row 0/IREF0: IREF1.1, U17.26
/Midnyte Display/Midnyte LED Row 0/IREF1: IREF2.1, U18.26
/Midnyte Display/Midnyte LED Row 0/IREF2: IREF3.1, U19.26
/Midnyte Display/Midnyte LED Row 0/RED0L: P12.1, U17.4
/Midnyte Display/Midnyte LED Row 0/RED0R: P13.1, U17.14
/Midnyte Display/Midnyte LED Row 0/RED1L: P12.2, U17.5
/Midnyte Display/Midnyte LED Row 0/RED1R: P13.2, U17.15
/Midnyte Display/Midnyte LED Row 0/RED2L: P12.3, U17.6
/Midnyte Display/Midnyte LED Row 0/RED2R: P13.3, U17.16
/Midnyte Display/Midnyte LED Row 0/RED3L: P12.4, U17.7
/Midnyte Display/Midnyte LED Row 0/RED3R: P13.4, U17.17
/Midnyte Display/Midnyte LED Row 0/RED4L: P12.5, U17.8
/Midnyte Display/Midnyte LED Row 0/RED4R: P13.5, U17.18
/Midnyte Display/Midnyte LED Row 0/RED5L: P12.6, U17.9
/Midnyte Display/Midnyte LED Row 0/RED5R: P13.6, U17.19
/Midnyte Display/Midnyte LED Row 0/RED6L: P12.7, U17.10
/Midnyte Display/Midnyte LED Row 0/RED6R: P13.7, U17.20
/Midnyte Display/Midnyte LED Row 0/RED7L: P12.8, U17.11
/Midnyte Display/Midnyte LED Row 0/RED7R: P13.8, U17.21
/Midnyte Display/Midnyte LED Row 0/SER1: U18.23, U19.2
/Midnyte Display/Midnyte LED Row 1/BLUE0L: P22.1, U22.4
/Midnyte Display/Midnyte LED Row 1/BLUE0R: P23.1, U22.14
/Midnyte Display/Midnyte LED Row 1/BLUE1L: P22.2, U22.5
/Midnyte Display/Midnyte LED Row 1/BLUE1R: P23.2, U22.15
/Midnyte Display/Midnyte LED Row 1/BLUE2L: P22.3, U22.6
/Midnyte Display/Midnyte LED Row 1/BLUE2R: P23.3, U22.16
/Midnyte Display/Midnyte LED Row 1/BLUE3L: P22.4, U22.7
/Midnyte Display/Midnyte LED Row 1/BLUE3R: P23.4, U22.17
/Midnyte Display/Midnyte LED Row 1/BLUE4L: P22.5, U22.8
/Midnyte Display/Midnyte LED Row 1/BLUE4R: P23.5, U22.18
/Midnyte Display/Midnyte LED Row 1/BLUE5L: P22.6, U22.9
/Midnyte Display/Midnyte LED Row 1/BLUE5R: P23.6, U22.19
/Midnyte Display/Midnyte LED Row 1/BLUE6L: P22.7, U22.10
/Midnyte Display/Midnyte LED Row 1/BLUE6R: P23.7, U22.20
/Midnyte Display/Midnyte LED Row 1/BLUE7L: P22.8, U22.11
/Midnyte Display/Midnyte LED Row 1/BLUE7R: P23.8, U22.21
/Midnyte Display/Midnyte LED Row 1/GREEN0L: P20.1, U21.4
/Midnyte Display/Midnyte LED Row 1/GREEN0R: P21.1, U21.14
/Midnyte Display/Midnyte LED Row 1/GREEN1L: P20.2, U21.5
/Midnyte Display/Midnyte LED Row 1/GREEN1R: P21.2, U21.15
/Midnyte Display/Midnyte LED Row 1/GREEN2L: P20.3, U21.6
/Midnyte Display/Midnyte LED Row 1/GREEN2R: P21.3, U21.16
/Midnyte Display/Midnyte LED Row 1/GREEN3L: P20.4, U21.7
/Midnyte Display/Midnyte LED Row 1/GREEN3R: P21.4, U21.17
/Midnyte Display/Midnyte LED Row 1/GREEN4L: P20.5, U21.8
/Midnyte Display/Midnyte LED Row 1/GREEN4R: P21.5, U21.18
/Midnyte Display/Midnyte LED Row 1/GREEN5L: P20.6, U21.9
/Midnyte Display/Midnyte LED Row 1/GREEN5R: P21.6, U21.19
/Midnyte Display/Midnyte LED Row 1/GREEN6L: P20.7, U21.10
/Midnyte Display/Midnyte LED Row 1/GREEN6R: P21.7, U21.20
/Midnyte Display/Midnyte LED Row 1/GREEN7L: P20.8, U21.11
/Midnyte Display/Midnyte LED Row 1/GREEN7R: P21.8, U21.21
/Midnyte Display/Midnyte LED Row 1/IREF0: IREF4.1, U20.26
/Midnyte Display/Midnyte LED Row 1/IREF1: IREF5.1, U21.26
/Midnyte Display/Midnyte LED Row 1/IREF2: IREF6.1, U22.26
/Midnyte Display/Midnyte LED Row 1/RED0L: P18.1, U20.4
/Midnyte Display/Midnyte LED Row 1/RED0R: P19.1, U20.14
/Midnyte Display/Midnyte LED Row 1/RED1L: P18.2, U20.5
/Midnyte Display/Midnyte LED Row 1/RED1R: P19.2, U20.15
/Midnyte Display/Midnyte LED Row 1/RED2L: P18.3, U20.6
/Midnyte Display/Midnyte LED Row 1/RED2R: P19.3, U20.16
/Midnyte Display/Midnyte LED Row 1/RED3L: P18.4, U20.7
/Midnyte Display/Midnyte LED Row 1/RED3R: P19.4, U20.17
/Midnyte Display/Midnyte LED Row 1/RED4L: P18.5, U20.8
/Midnyte Display/Midnyte LED Row 1/RED4R: P19.5, U20.18
/Midnyte Display/Midnyte LED Row 1/RED5L: P18.6, U20.9
/Midnyte Display/Midnyte LED Row 1/RED5R: P19.6, U20.19
/Midnyte Display/Midnyte LED Row 1/RED6L: P18.7, U20.10
/Midnyte Display/Midnyte LED Row 1/RED6R: P19.7, U20.20
/Midnyte Display/Midnyte LED Row 1/RED7L: P18.8, U20.11
/Midnyte Display/Midnyte LED Row 1/RED7R: P19.8, U20.21
/Midnyte Display/Midnyte LED Row 1/SER1: U21.23, U22.2
/Midnyte Display/Midnyte LED Row 2/BLUE0L: P28.1, U25.4
/Midnyte Display/Midnyte LED Row 2/BLUE0R: P29.1, U25.14
/Midnyte Display/Midnyte LED Row 2/BLUE1L: P28.2, U25.5
/Midnyte Display/Midnyte LED Row 2/BLUE1R: P29.2, U25.15
/Midnyte Display/Midnyte LED Row 2/BLUE2L: P28.3, U25.6
/Midnyte Display/Midnyte LED Row 2/BLUE2R: P29.3, U25.16
/Midnyte Display/Midnyte LED Row 2/BLUE3L: P28.4, U25.7
/Midnyte Display/Midnyte LED Row 2/BLUE3R: P29.4, U25.17
/Midnyte Display/Midnyte LED Row 2/BLUE4L: P28.5, U25.8
/Midnyte Display/Midnyte LED Row 2/BLUE4R: P29.5, U25.18
/Midnyte Display/Midnyte LED Row 2/BLUE5L: P28.6, U25.9
/Midnyte Display/Midnyte LED Row 2/BLUE5R: P29.6, U25.19
/Midnyte Display/Midnyte LED Row 2/BLUE6L: P28.7, U25.10
/Midnyte Display/Midnyte LED Row 2/BLUE6R: P29.7, U25.20
/Midnyte Display/Midnyte LED Row 2/BLUE7L: P28.8, U25.11
/Midnyte Display/Midnyte LED Row 2/BLUE7R: P29.8, U25.21
/Midnyte Display/Midnyte LED Row 2/GREEN0L: P26.1, U24.4
/Midnyte Display/Midnyte LED Row 2/GREEN0R: P27.1, U24.14
/Midnyte Display/Midnyte LED Row 2/GREEN1L: P26.2, U24.5
/Midnyte Display/Midnyte LED Row 2/GREEN1R: P27.2, U24.15
/Midnyte Display/Midnyte LED Row 2/GREEN2L: P26.3, U24.6
/Midnyte Display/Midnyte LED Row 2/GREEN2R: P27.3, U24.16
/Midnyte Display/Midnyte LED Row 2/GREEN3L: P26.4, U24.7
/Midnyte Display/Midnyte LED Row 2/GREEN3R: P27.4, U24.17
/Midnyte Display/Midnyte LED Row 2/GREEN4L: P26.5, U24.8
/Midnyte Display/Midnyte LED Row 2/GREEN4R: P27.5, U24.18
/Midnyte Display/Midnyte LED Row 2/GREEN5L: P26.6, U24.9
/Midnyte Display/Midnyte LED Row 2/GREEN5R: P27.6, U24.19
/Midnyte Display/Midnyte LED Row 2/GREEN6L: P26.7, U24.10
/Midnyte Display/Midnyte LED Row 2/GREEN6R: P27.7, U24.20
/Midnyte Display/Midnyte LED Row 2/GREEN7L: P26.8, U24.11
/Midnyte Display/Midnyte LED Row 2/GREEN7R: P27.8, U24.21
/Midnyte Display/Midnyte LED Row 2/IREF0: IREF7.1, U23.26
/Midnyte Display/Midnyte LED Row 2/IREF1: IREF8.1, U24.26
/Midnyte Display/Midnyte LED Row 2/IREF2: IREF9.1, U25.26
/Midnyte Display/Midnyte LED Row 2/RED0L: P24.1, U23.4
/Midnyte Display/Midnyte LED Row 2/RED0R: P25.1, U23.14
/Midnyte Display/Midnyte LED Row 2/RED1L: P24.2, U23.5
/Midnyte Display/Midnyte LED Row 2/RED1R: P25.2, U23.15
/Midnyte Display/Midnyte LED Row 2/RED2L: P24.3, U23.6
/Midnyte Display/Midnyte LED Row 2/RED2R: P25.3, U23.16
/Midnyte Display/Midnyte LED Row 2/RED3L: P24.4, U23.7
/Midnyte Display/Midnyte LED Row 2/RED3R: P25.4, U23.17
/Midnyte Display/Midnyte LED Row 2/RED4L: P24.5, U23.8
/Midnyte Display/Midnyte LED Row 2/RED4R: P25.5, U23.18
/Midnyte Display/Midnyte LED Row 2/RED5L: P24.6, U23.9
/Midnyte Display/Midnyte LED Row 2/RED5R: P25.6, U23.19
/Midnyte Display/Midnyte LED Row 2/RED6L: P24.7, U23.10
/Midnyte Display/Midnyte LED Row 2/RED6R: P25.7, U23.20
/Midnyte Display/Midnyte LED Row 2/RED7L: P24.8, U23.11
/Midnyte Display/Midnyte LED Row 2/RED7R: P25.8, U23.21
/Midnyte Display/Midnyte LED Row 2/SER1: U24.23, U25.2
/Midnyte Display/ROW0: U1.20, U11.14
/Midnyte Display/ROW0L: P6.1, U11.15
/Midnyte Display/ROW0R: P7.1, U14.15
/Midnyte Display/ROW1: U1.21, U12.14
/Midnyte Display/ROW1L: P6.2, U11.1
/Midnyte Display/ROW1R: P7.2, U14.1
/Midnyte Display/ROW2: U1.25, U13.14
/Midnyte Display/ROW2L: P6.3, U11.2
/Midnyte Display/ROW2R: P7.3, U14.2
/Midnyte Display/ROW3L: P6.4, U11.3
/Midnyte Display/ROW3R: P7.4, U14.3
/Midnyte Display/ROW4L: P6.5, U11.4
/Midnyte Display/ROW4R: P7.5, U14.4
/Midnyte Display/ROW5L: P6.6, U11.5
/Midnyte Display/ROW5R: P7.6, U14.5
/Midnyte Display/ROW6L: P6.7, U11.6
/Midnyte Display/ROW6R: P7.7, U14.6
/Midnyte Display/ROW7L: P6.8, U11.7
/Midnyte Display/ROW7R: P7.8, U14.7
/Midnyte Display/ROW8L: P8.1, U12.15
/Midnyte Display/ROW8R: P9.1, U15.15
/Midnyte Display/ROW9L: P8.2, U12.1
/Midnyte Display/ROW9R: P9.2, U15.1
/Midnyte Display/ROW10L: P8.3, U12.2
/Midnyte Display/ROW10R: P9.3, U15.2
/Midnyte Display/ROW11L: P8.4, U12.3
/Midnyte Display/ROW11R: P9.4, U15.3
/Midnyte Display/ROW12L: P8.5, U12.4
/Midnyte Display/ROW12R: P9.5, U15.4
/Midnyte Display/ROW13L: P8.6, U12.5
/Midnyte Display/ROW13R: P9.6, U15.5
/Midnyte Display/ROW14L: P8.7, U12.6
/Midnyte Display/ROW14R: P9.7, U15.6
/Midnyte Display/ROW15L: P8.8, U12.7
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

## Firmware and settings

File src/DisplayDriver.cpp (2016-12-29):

#include "DisplayDriver.hpp"

#define BLANK_DDR    DDRD
#define BLANK_PIN    PD7
#define BLANK_PORT   PORTD
#define GSCLK_DDR    DDRC
#define GSCLK_PIN    PC6
#define GSCLK_PORT   PORTC
#define XLAT_DDR     DDRB
#define XLAT_PIN     PB5
#define XLAT_PORT    PORTB

// -----------------------------------------------------------------------------
// Construction
// -----------------------------------------------------------------------------
DisplayDriver::DisplayDriver() : brightness(0) {
	// Disable interrupts globally
	cli();


	// -------------------------------------------------------------------------
	// Timer0 - Row strobe
	// -------------------------------------------------------------------------

	// Timer control registers
	TCCR0A &= ~_BV(COM0A1);  // Normal port operation
	TCCR0A &= ~_BV(COM0A0);
	TCCR0A &= ~_BV(COM0B1);  // Normal port operation
	TCCR0A &= ~_BV(COM0B0);
	// Reserved
	// Reserved
	TCCR0A &= ~_BV(WGM01);   // Normal timer/counter operation
	TCCR0A &= ~_BV(WGM00);

	TCCR0B &= ~_BV(FOC0A);   // No forced output compare
	TCCR0B &= ~_BV(FOC0B);
	// Reserved
	// Reserved
	TCCR0B &= ~_BV(WGM02);   // Normal timer/counter operation
	TCCR0B &= ~_BV(CS02);    // Prescalar = 1/1
	TCCR0B &= ~_BV(CS01);
	TCCR0B |= _BV(CS00);

	// Timer count and alarm registers
	TCNT0 = 0;                 // Set timer count to 0
	//OCR0A = ROW_STROBE_TIMER;  // Set the output compare count
	OCR0A = 128;  // Set the output compare count
	OCR0B = 0;                 // Set the output compare count

	// Timer interrupt masks
	TIMSK0 |= _BV(OCIE0A);   // Enable output compare A interrupts
	TIMSK0 &= ~_BV(OCIE0B);  // Disable output compare B interrupts
	TIMSK0 |= _BV(TOIE0);

	// Timer interrupt flag register
	TIFR0 |= _BV(OCF0A);     // Enable output compare A interrupts
	TIFR0 &= ~_BV(OCF0B);    // Disable output compare B interrupts
	TIFR0 |= _BV(TOV0);      // Enable timer0 overflow interrupts


	// -------------------------------------------------------------------------
	// Timer1 - XLAT(OCR1A) / BLANK(OCR1B)
	// -------------------------------------------------------------------------

	// Timer control registers
	TCCR1A &= ~_BV(COM1A1);  // Normal port operatatoin on OC1A
	TCCR1A &= ~_BV(COM1A0);
	TCCR1A |= _BV(COM1B1);   // Set OC1B (BLANK) on compare match (non-inverting output)
	TCCR1A &= ~_BV(COM1B0);
	TCCR1A &= ~_BV(COM1C1);  // Normal port operation
	TCCR1A &= ~_BV(COM1C0);
	TCCR1A &= ~_BV(WGM11);   // Normal timer/counter operation
	TCCR1A &= ~_BV(WGM10);   // PWM, phase & frequency correct, ICR1 is TOP

	TCCR1B &= ~_BV(ICNC1);   // Disable input capture noice canceller
	TCCR1B &= ~_BV(ICES1);   // Falling edge input capture trigger
	// Reserved
	TCCR1B |= _BV(WGM13);    // PWM, phase & frequency correct, ICR1 is TOP
	TCCR1B &= ~_BV(WGM12);   // PWM, phase & frequency correct, ICR1 is TOP
	TCCR1B &= ~_BV(CS12);    // Prescalar = 1/1
	TCCR1B &= ~_BV(CS11);
	TCCR1B |= _BV(CS10);

	TCCR1C &= ~_BV(FOC1A);   // No forced output compare
	TCCR1C &= ~_BV(FOC1B);
	TCCR1C &= ~_BV(FOC1C);
	// Reserved
	// Reserved
	// Reserved
	// Reserved
	// Reserved

	// Timer count and alarm registers
	TCNT1H = 0;      // Must write high byte first
	TCNT1L = 0;
	OCR1AH = 0;      // Set the output compare count
	OCR1AL = 1;      // Duty cycle for OC1A (XLAT); inside BLANK
	OCR1BH = 0;      // Set the output compare count
	OCR1BL = 2;      // Duty cycle for OC1B (BLANK)
	OCR1CH = 0;      // Set the output compare count
	OCR1CL = 0;
	ICR1H = 0x20;    // Default PWM period (8192)
	ICR1L = 0x0;

	// Timer interrupt masks
	// Reserved
	// Reserved
	TIMSK1 &= ~_BV(ICIE1);   // Disable input capture interrupts
	// Reserved
	TIMSK1 &= ~_BV(OCIE1C);  // Disable output compare C interrupts
	TIMSK1 &= ~_BV(OCIE1B);  // Disable output compare B interrupts
	TIMSK1 &= ~_BV(OCIE1A);  // Disable output compare A interrupts
	//TIMSK1 |= _BV(TOIE1);    // Enable timer overflow interrupts

	// Timer interrupt flag register
	// Reserved
	// Reserved
	TIFR1 &= ~_BV(ICF1);     // Clear interrupts
	// Reserved
	TIFR1 &= ~_BV(OCF1C);
	TIFR1 &= ~_BV(OCF1A);
	TIFR1 &= ~_BV(OCF1B);
	//TIFR1 &= ~_BV(TOV1);     // Enable Timer 1 overflow interrupts


	// -------------------------------------------------------------------------
	// Timer3 - PWM brightness control (GSCLK)
	// -------------------------------------------------------------------------

	// Timer control registers
	TCCR3A &= ~_BV(COM3A1);  // Toggle OC3A on compare match
	TCCR3A |= _BV(COM3A0);
	TCCR3A &= ~_BV(COM3B1);  // Normal port operation
	TCCR3A &= ~_BV(COM3B0);
	TCCR3A &= ~_BV(COM3C1);  // Normal port operation
	TCCR3A &= ~_BV(COM3C0);
	TCCR3A &= ~_BV(WGM31);   // Normal timer/counter mode of operation
	TCCR3A &= ~_BV(WGM30);   // Normal timer/counter mode of operation

	TCCR3B &= ~_BV(ICNC3);   // Disable input capture noice canceller
	TCCR3B &= ~_BV(ICES3);   // Falling edge input capture trigger
	// Reserved
	TCCR3B |= _BV(WGM33);    // Normal timer/counter mode of operation
	TCCR3B |= _BV(WGM32);    // Normal timer/counter mode of operation
	TCCR3B &= ~_BV(CS32);    // No prescalar
	TCCR3B &= ~_BV(CS31);
	TCCR3B |= _BV(CS30);

	TCCR3C &= ~_BV(FOC3A);   // No forced output compare
	// Reserved
	// Reserved
	// Reserved
	// Reserved
	// Reserved
	// Reserved
	// Reserved

	// Timer count and alarm registers
	TCNT3H = 0;      // Must write high byte first
	TCNT3L = 0;
	OCR3AH = 0;      // Set the output compare count
	OCR3AL = 0;
	OCR3BH = 0;      // Set the output compare count
	OCR3BL = 0;
	OCR3CH = 0;      // Set the output compare count
	OCR3CL = 0;
	ICR3H = 0;
	ICR3L = 0;

	// Timer interrupt masks
	// Reserved
	// Reserved
	TIMSK3 &= ~_BV(ICIE3);   // Disable input capture interrupts
	// Reserved
	TIMSK3 &= ~_BV(OCIE3C);  // Disable output compare C interrupts
	TIMSK3 &= ~_BV(OCIE3B);  // Disable output compare B interrupts
	TIMSK3 &= ~_BV(OCIE3A);  // Disable output compare A interrupts
	TIMSK3 &= ~_BV(TOIE3);   // Disable timer overflow interrupts

	// Timer interrupt flag register
	// Reserved
	// Reserved
	TIFR3 &= ~_BV(ICF3);     // Clear interrupts
	// Reserved
	TIFR3 |= _BV(OCF3C);     // Clear output compare C match interrupts
	TIFR3 |= _BV(OCF3B);     // Clear output compare B match interrupts
	TIFR3 |= _BV(OCF3A);     // Clear output compare A match interrupts
	TIFR3 |= _BV(TOV3);      // Clear Timer 3 overflow interrupts


	// -------------------------------------------------------------------------
	// SPI
	// -------------------------------------------------------------------------

	DDRB |= _BV(PB0);     // SS
	DDRB |= _BV(PB1);     // SCLK
	DDRB |= _BV(PB2);     // MOSI
	DDRB &= ~_BV(PB3);    // MISO
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

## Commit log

2016-11-06 Initial commit for board design
    [midnyte-B_CrtYd.gbr, midnyte-B_Cu.gbl, midnyte-B_Fab.gbr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]
2016-11-06 Updated the README with a little information about the device
2016-11-07 Moved setup of display driver pins to DisplayDriver construction
2016-12-29 Move 'currentColor' ownership to Display + cleanup
